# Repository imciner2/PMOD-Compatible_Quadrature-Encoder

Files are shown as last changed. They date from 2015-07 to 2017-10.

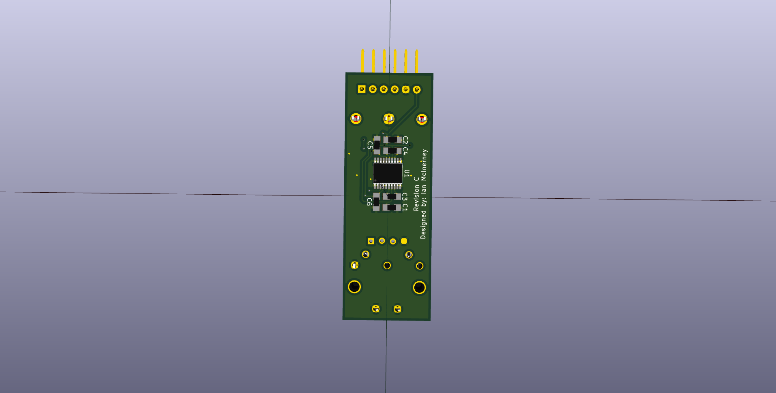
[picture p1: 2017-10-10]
2-Hardware/SingleEncoder/BoardBottom.png

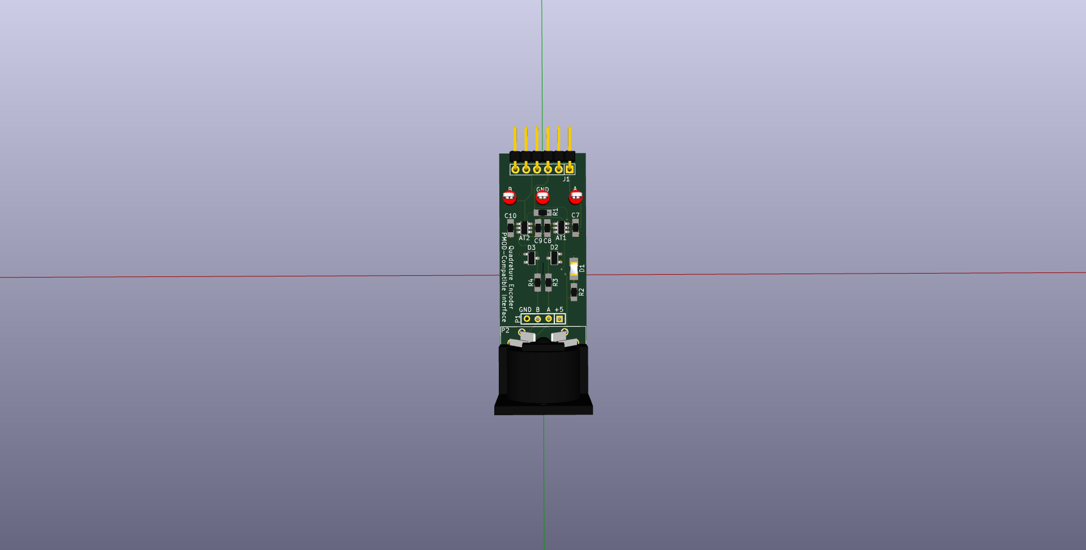
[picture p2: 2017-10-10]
2-Hardware/SingleEncoder/BoardTop.png

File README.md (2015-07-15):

# PMOD-Compatible_Quadrature-Encoder
Circuit board to interface a 5-pin DIN quadrature encoder to a PMOD port.

## Library Housekeeping

### To read in any changes from the Kicad library repository to this one:

1. Fetch the changes

    ``` git fetch libraries ```

2. Merge the changes

    ``` git merge -s subtree --squash libraries/master ```

3. Commit the changes

    ``` git commit -m "Updated libraries directory" ```

### To push any of the changes from this project to the Kicad libarary repository

1. Create commits for the changes (make them seperate from everything else)

2. Create a new branch locally

    ``` git checkout -b library-work libraries/master ```

3. Select the commits to add to the library (The command shown below will use the 5th commit before the current revision, simply modify the 5 to change which commit is referenced)

    ``` git cherry-pick -x --strategy=subtree master~5 ```

4. Push the new changes back to the libraries repository

    ``` git push libraries library-work:master ```

5. Go back to the working repository

    ``` git checkout master ```

6. Delete the branch you just used

    ``` git branch -D library-work ```

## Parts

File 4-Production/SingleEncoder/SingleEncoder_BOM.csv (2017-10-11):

Source: | /home/imcinerney/Documents/Github/PMOD-Compatible_Quadrature-Encoder/2-Hardware/SingleEncoder/SingleEncoder.sch
Date: | Wed 11 Oct 2017 11:40:44 PM BST
Tool: | Eeschema 4.0.6
Generator: | /home/imcinerney/Documents/Github/KiCad-Libraries/BOM_Scripts/bom_csv_grouped_by_value.py
Component Count: | 23
Item | Qty | Reference(s) | Value | LibPart | Footprint | Datasheet | DigikeyNumber | Manufacturer | ManufacturerNumber
1 | 2 | AT1, AT2 | TXB0101 | LogicDevices:TXB0101 | SMD:SOT-23-6 |  | 296-21664-1-ND | Texas Instruments | TXB0101DBVR
2 | 2 | C1, C2 | 15uF | Passives:CAP | SMD:SMD_0805 |  | 445-14362-1-ND | TDK Corporation | C2012X5R1A156M085AC
3 | 2 | C3, C4 | 2.2uF | Passives:CAP | SMD:SMD_0805 |  | 311-3425-1-ND | Yageo | CC0805KRX5R6BB225
4 | 2 | C5, C6 | 22uF | Passives:CAP | SMD:SMD_0805 |  | 1276-6786-1-ND | Samsung Electro-Mechanics America, Inc. | CL21A226KPCLRNC
5 | 4 | C7, C8, C9, C10 | 0.1uF | Passives:CAP | SMD:SMD_0805 |  | 311-1141-1-ND | Yageo | CC0805KRX7R8BB104
6 | 1 | D1 | RED | Diodes:D_LED | LEDs:LED_1206 |  | 754-1137-1-ND | Kingbright | APT3216EC
7 | 2 | D2, D3 | PLVA653A | Diodes:D_ZENER | Diodes:DIODE_SOT-23-3 |  | 568-6472-1-ND | NXP | PLVA653A,215
8 | 1 | J1 | PMOD_SINGLE | PMOD:PMOD_SINGLE | Connectors:PMOD_SINGLE_MALE |  | 609-3313-ND | FCI | 68016-106HLF
9 | 1 | P1 | CONN_01X06 | SingleEncoder-cache:CONN_01X06 | Connectors:DIN_CUI_SDS-50J |  | CP-2350-ND | CUI Inc | SDS-50J
10 | 1 | P2 | CONN_01X04 | SingleEncoder-cache:CONN_01X04 | Connectors:CONN_2.54mm_1x4
11 | 1 | R1 | 10k | Passives:RES | SMD:SMD_0805 |  | RMCF0805FT10K0CT-ND | Stackpole Electronics Inc | RMCF0805FT10K0
12 | 1 | R2 | 330 | Passives:RES | SMD:SMD_0805 |  | P330CCT-ND | Panasonic Electronic Components | ERJ-6ENF3300V
13 | 2 | R3, R4 | 220 | Passives:RES | SMD:SMD_0805 |  | P220CCT-ND | Panasonic Electronic Components | ERJ-6ENF2200V
14 | 1 | U1 | TPS60131 | PowerComponents:TPS60131 | SMD:SSOP_20_4.5mm_6.6mm_0.65mm_PWP | http://www.ti.com/lit/ds/symlink/tps60130.pdf | 296-2272-5-ND | Texas Instruments | TPS60131PWP

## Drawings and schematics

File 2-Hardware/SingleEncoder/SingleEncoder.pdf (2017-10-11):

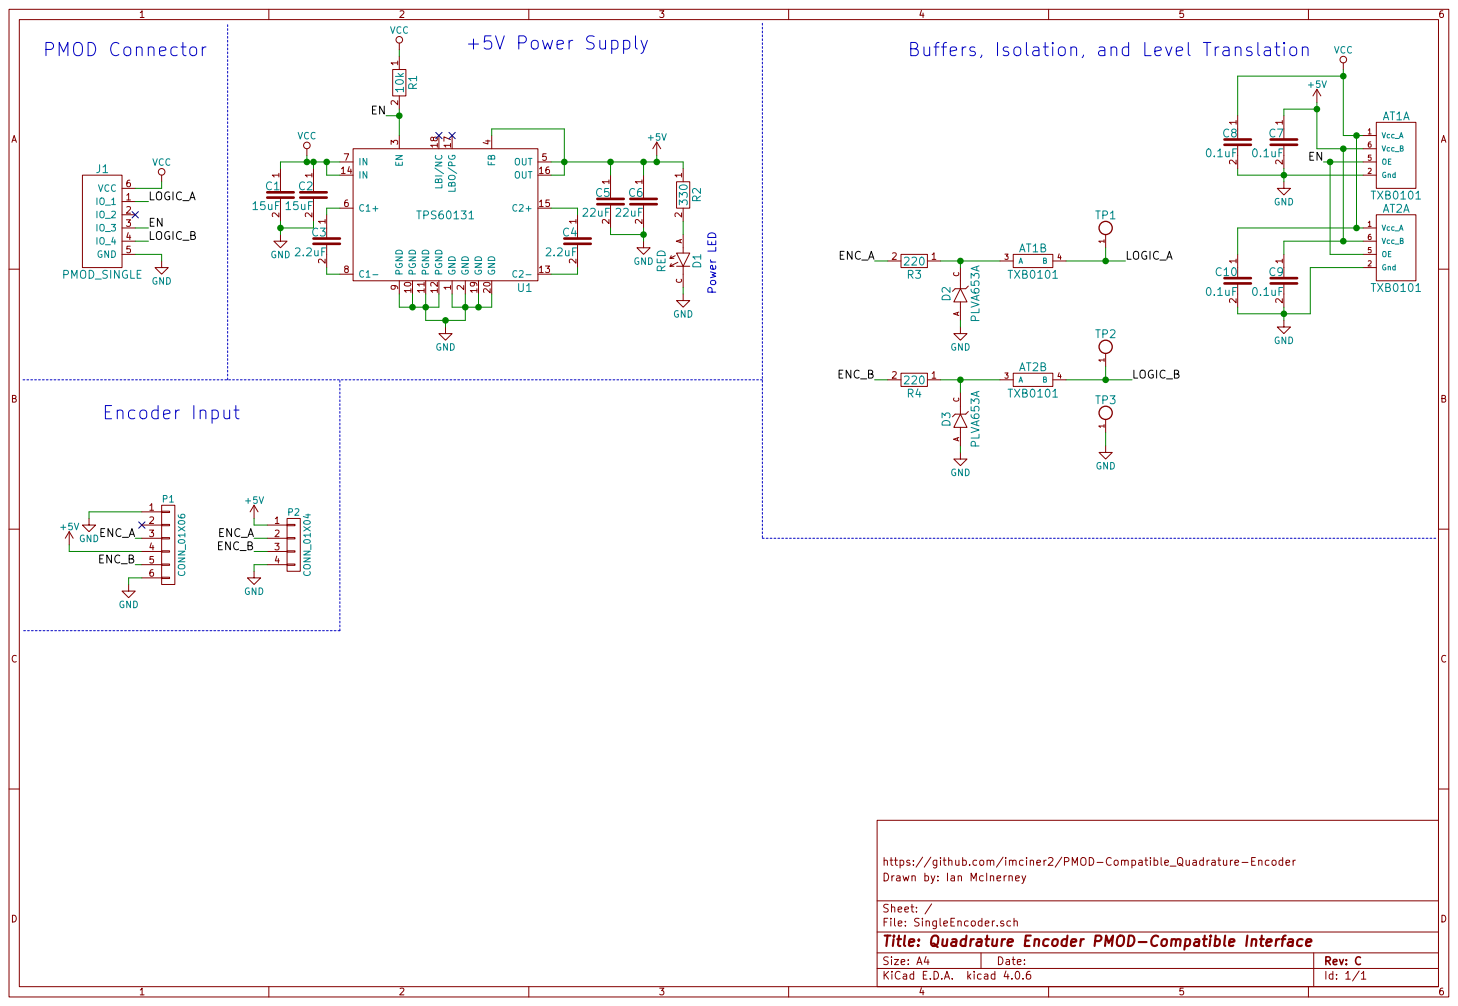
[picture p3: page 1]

Buffers, Isolation, and Level Translation

9 PGND 10 GND 20 PGND 11 PGND 12 C2- 13

https://github.com/imciner2/PMOD-Compatible_Quadrature-Encoder GND

File: SingleEncoder.sch Sheet: / Drawn by: Ian McInerney

Id: 1/1 Title: Quadrature Encoder PMOD-Compatible Interface

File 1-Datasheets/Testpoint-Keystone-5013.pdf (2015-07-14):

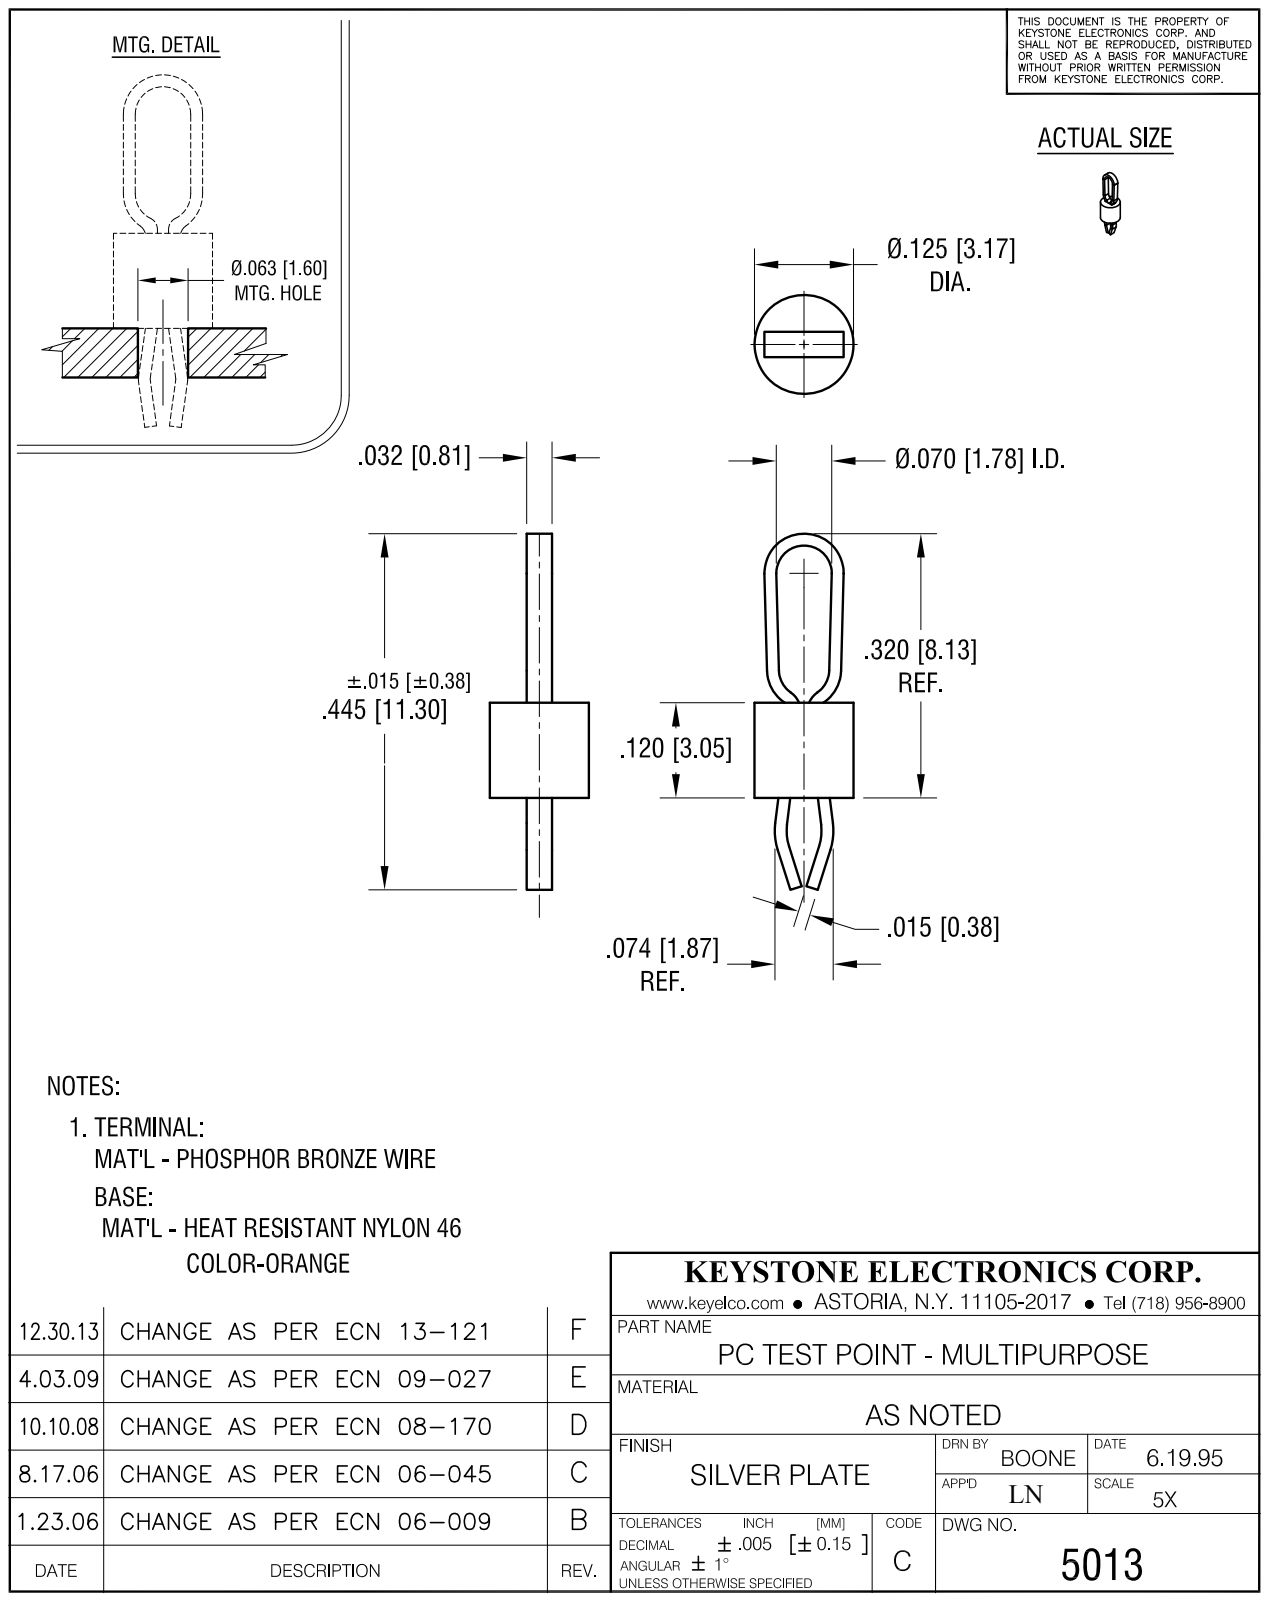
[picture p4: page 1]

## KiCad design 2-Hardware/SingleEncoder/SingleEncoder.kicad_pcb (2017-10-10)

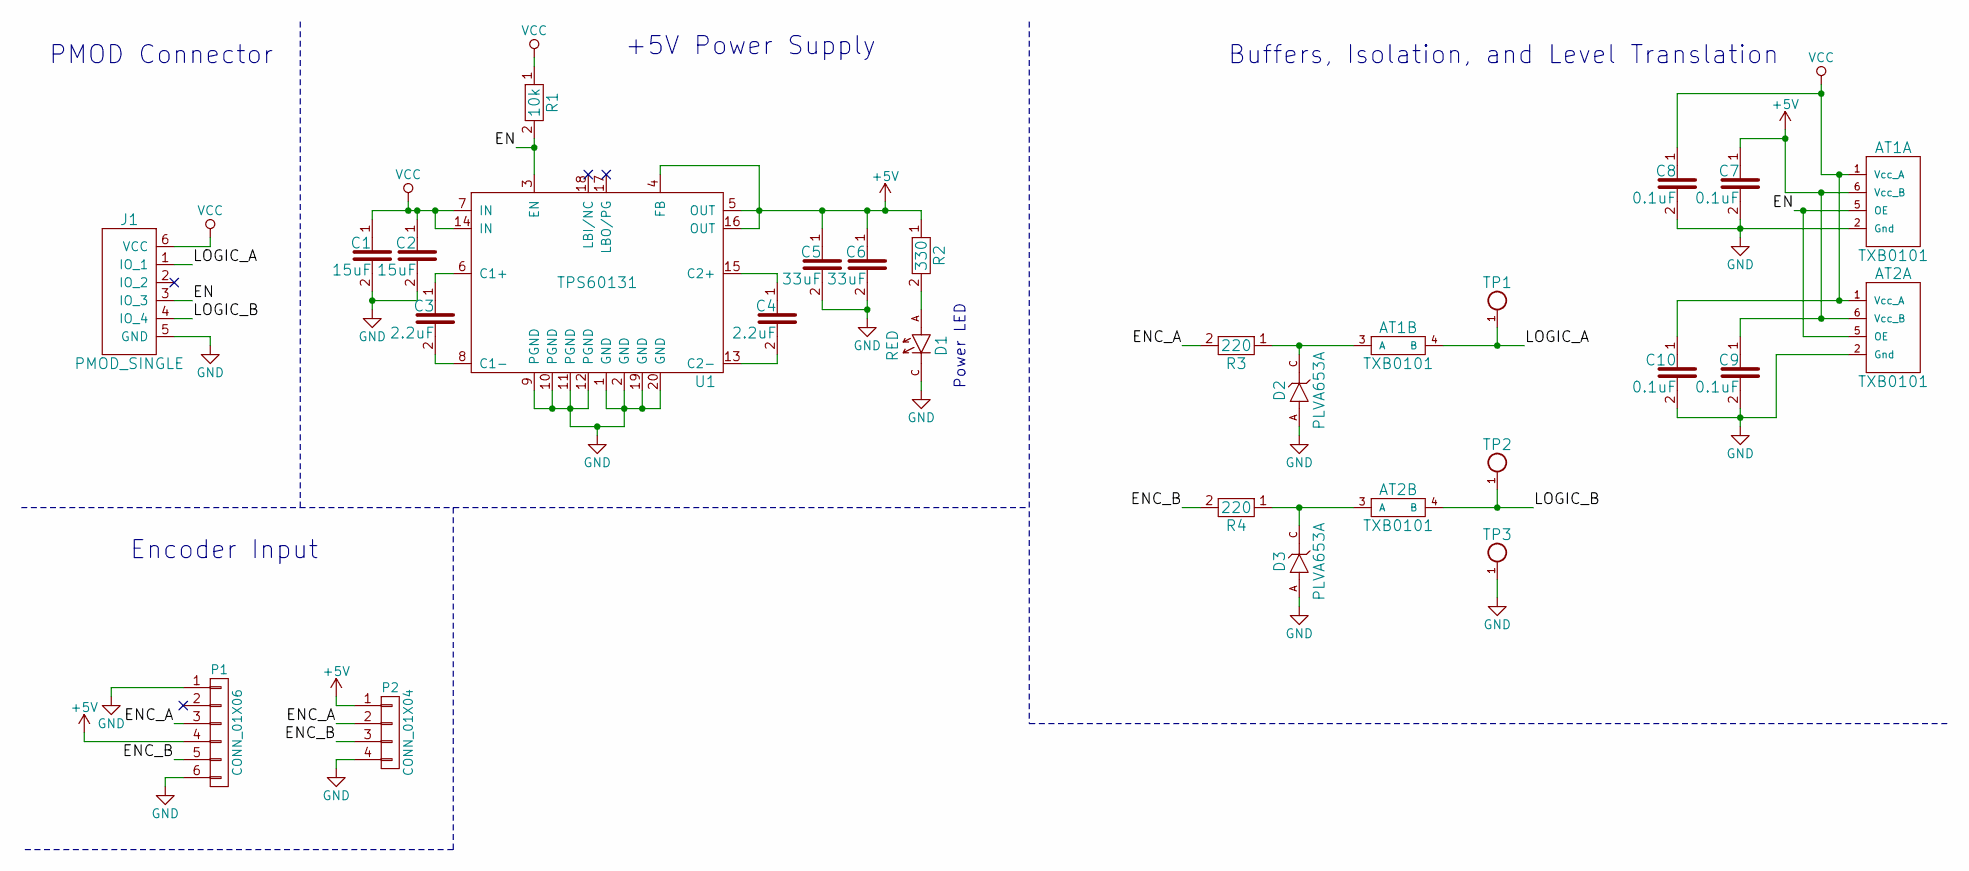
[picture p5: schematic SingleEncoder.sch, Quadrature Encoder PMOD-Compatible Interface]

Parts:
AT1, AT2: TXB0101; SOT-23-6; DigikeyNumber 296-21664-1-ND
C1, C2: 15uF; SMD_0805; DigikeyNumber 445-14362-1-ND
C3, C4: 2.2uF; SMD_0805; DigikeyNumber 445-1588-1-ND
C5, C6: 33uF; SMD_0805; DigikeyNumber 445-8238-1-ND
C7, C8, C9, C10: 0.1uF; SMD_0805; DigikeyNumber 311-1141-1-ND
D1: RED; LED_1206; DigikeyNumber 754-1137-1-ND
D2, D3: PLVA653A; DIODE_SOT-23-3; DigikeyNumber 568-6472-1-ND
J1: PMOD_SINGLE; PMOD_SINGLE_MALE; DigikeyNumber 609-3313-ND
P1: CONN_01X06; DIN_CUI_SDS-50J; DigikeyNumber CP-2350-ND
P2: CONN_01X04; CONN_2.54mm_1x4
R1: 10k; SMD_0805; DigikeyNumber P10.0KCCT-ND
R2: 330; SMD_0805; DigikeyNumber P330CCT-ND
R3, R4: 220; SMD_0805; DigikeyNumber P220CCT-ND
TP1, TP2: TEST_POINT; TESTPOINT_063; DigikeyNumber 36-5013-ND
TP3: TEST_POINT; TESTPOINT_063; DigikeyNumber 36-5011-ND
U1: TPS60131; SSOP_20_4.5mm_6.6mm_0.65mm_PWP; DigikeyNumber 296-2272-5-ND

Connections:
+5V: AT1.6 (Vcc_B), AT2.6 (Vcc_B), C5.1, C6.1, C7.1, C9.1, P1.4, P2.1, R2.1, U1.4 (FB), U1.5 (OUT), U1.16 (OUT)
/EN: AT1.5 (OE), AT2.5 (OE), J1.3 (IO_3), R1.2, U1.3 (EN)
/ENC_A: P1.3, P2.2, R3.2
/ENC_B: P1.5, P2.3, R4.2
/LOGIC_A: AT1.4 (B), J1.1 (IO_1), TP1.1
/LOGIC_B: AT2.4 (B), J1.4 (IO_4), TP2.1
GND: AT1.2 (Gnd), AT2.2 (Gnd), C1.2, C2.2, C5.2, C6.2, C7.2, C8.2, C9.2, C10.2, D1.C, D2.A, D3.A, J1.5 (GND), P1.1, P1.6, P2.4, TP3.1, U1.1 (GND), U1.2 (GND), U1.9 (PGND), U1.10 (PGND), U1.11 (PGND), U1.12 (PGND), U1.19 (GND), U1.20 (GND)
unnamed: AT1.3 (A), D2.C, R3.1
unnamed: AT2.3 (A), D3.C, R4.1
unnamed: C3.1, U1.6 (C1+)
unnamed: C3.2, U1.8 (C1-)
unnamed: C4.1, U1.15 (C2+)
unnamed: C4.2, U1.13 (C2-)
unnamed: D1.A, R2.2
VCC: AT1.1 (Vcc_A), AT2.1 (Vcc_A), C1.1, C2.1, C8.1, C10.1, J1.6 (VCC), R1.1, U1.7 (IN), U1.14 (IN)

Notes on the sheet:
PMOD Connector
+5V Power Supply
Encoder Input
Buffers, Isolation, and Level Translation
Power LED

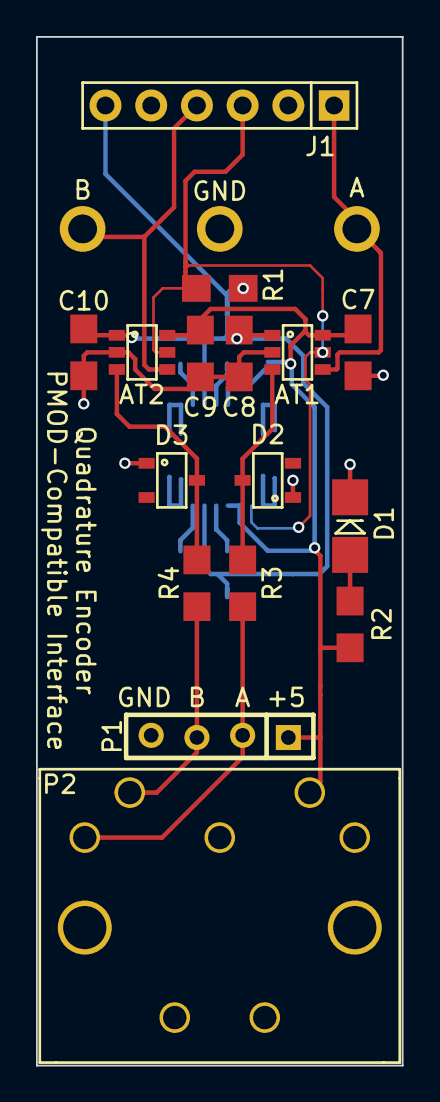
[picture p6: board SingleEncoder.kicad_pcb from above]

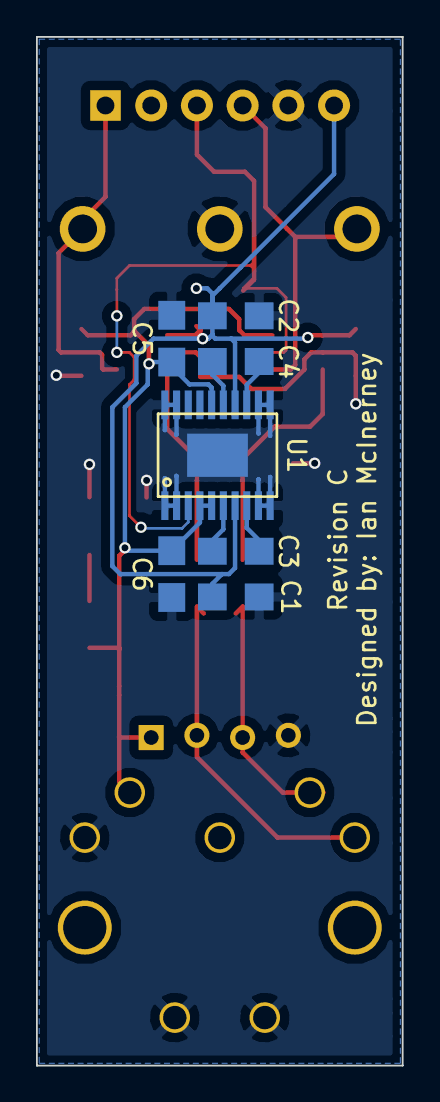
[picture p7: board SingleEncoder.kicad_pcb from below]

Board: 2 copper layers, 20.3 x 57.2 mm, 26 parts (7 on the bottom side), 15 nets.

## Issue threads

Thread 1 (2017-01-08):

Delayed level shifting

imciner2, 2017-01-08:
The signals passing through the opto-isolator are delayed, and the rise-time and fall-time are different durations. This will produce inaccurate readings for the encoder.

imciner2, 2017-01-22:
Changing out the optoisolator part for a 2-bit voltage level shifter (TI TXB0102).

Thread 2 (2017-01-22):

Holes too small on PMOD Connector

imciner2, 2017-01-22:
Version 1 has holes too small for the pins on the PMOD connector.

imciner2, 2017-01-24:
Fixed in library update from earlier.

Closed 2017-01-24.

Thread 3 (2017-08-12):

Fix AT1 Footprint

imciner2, 2017-08-12:
The current board footprint has the pads to far apart (pins are not able to touch the pad) and the pads are too long.

imciner2, 2017-08-12:
Transition the level shifting to 2 individual shifters (in a SOT23 package) to make the assembly easier.

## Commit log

2015-07-10 Kicad libraries initial commit
2015-07-14 Added PMOD schematic symbols
2015-07-14 Added NPN and PNP schematic symbols
2015-07-14 Added TI charge pump devices
2015-07-14 Schematic for single encoder PMOD
    [SingleEncoder.sch]
2015-07-15 Fixed issue with diode footprint file
2015-07-15 PMOD-Compatible connector footprints
2015-07-15 Footprint for a CUI SDS-50J DIN Connector
2015-07-15 Footprint for a testpoint
2015-07-15 Started footprint association
    [SingleEncoder.sch]
2015-07-16 Added 3D models for DIN connectors
2015-07-16 Associated DIN footprint
    [SingleEncoder.sch]
2015-07-16 Finished footprint association
    [SingleEncoder.sch]
2015-07-17 Fixed pin numbering issue
2015-07-17 Started circuit board layout
    [SingleEncoder.kicad_pcb, SingleEncoder.sch]
2015-07-17 Finalized BOM
    [SingleEncoder.csv, SingleEncoder.kicad_pcb, SingleEncoder.sch]
2015-07-17 Board production files
    [SingleEncoder-B_Cu.gbr, SingleEncoder-B_Mask.gbr, SingleEncoder-B_SilkS.gbr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]
2015-07-17 Completed single encoder files
    [SingleEncoder.csv]
2015-08-03 Added 4-pin connector behind the DIN connector
    [SingleEncoder-B_Cu.gbr, SingleEncoder-B_Mask.gbr, SingleEncoder-B_SilkS.gbr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]
2017-01-22 Replaced Opto-isolator with I2C level shifter
    [SingleEncoder.sch]
2017-01-22 Changed level translator
    [SingleEncoder.csv, SingleEncoder.sch]
2017-01-23 Associated footprints, reimported to board. Layout not done.
    [SingleEncoder.kicad_pcb, SingleEncoder.sch]
2017-07-26 Updated board layout to use level shifter
    [SingleEncoder-B.Cu.gbr, SingleEncoder-B.Mask.gbr, SingleEncoder-B.SilkS.gbr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]
2017-07-26 Updated PMOD connector holes
    [SingleEncoder-B.Cu.gbr, SingleEncoder-B.Mask.gbr, SingleEncoder-B.SilkS.gbr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]
2017-10-09 Updated isolation circuit
    - Swapped TXB0102 for 2 TXB0101
    - Re-did board layout to accomodate new parts
    [SingleEncoder.csv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]
2017-10-10 Revised layout and created BOM
    [SingleEncoder.csv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]
2017-10-10 Updated production files with Rev C part
    [SingleEncoder.csv, SingleEncoder_BOM.csv]
2017-10-11 Update BOM to make sure all parts are in stock.
    [SingleEncoder.csv, SingleEncoder.sch, SingleEncoder_BOM.csv]
